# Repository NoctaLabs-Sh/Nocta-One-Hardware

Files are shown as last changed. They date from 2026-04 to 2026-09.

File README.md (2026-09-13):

# Nocta Hardware

Open hardware for the Nocta vault: an offline password and credential manager
with a 2.7 inch e-ink screen, optional Bluetooth LE, and no cloud service
behind it.

This repository is the design, not a product. The device is a prototype, it is
not for sale, and there is no ship date.

Built by [Nocta Labs](https://noctalabs.sh), Leuven, Belgium.

## What is in here

| Path | What it is |
| --- | --- |
| `Hardware/OpenVault.kicad_sch` | Schematic, KiCad |
| `Hardware/Schematic.pdf` | The same schematic, readable without KiCad |
| `Hardware/OpenVault.kicad_pcb` | Board layout, KiCad |
| `Hardware/production/` | Fabrication packages: gerbers, positions, BOMs |
| `Hardware/3D/` | STEP models for individual component packages |
| `Hardware/Datasheets/` | Datasheets for the parts used |
| `Hardware/Footprints/`, `Symbols/` | Project libraries |

## What is not in here yet

- **Firmware.** Still being written. It will be published when it is worth
  reading, and the licence for it is not decided.
- **The enclosure.** No named enclosure model is published yet.
- **Photographs.** Coming with the next write-up.

## Licence

[CERN Open Hardware Licence Version 2, Strongly Reciprocal](LICENSE)
(`CERN-OHL-S-2.0`). Strongly reciprocal means anything you make from this and
distribute has to stay open under the same terms. That is deliberate.

## Reading the files

Open `Hardware/OpenVault.kicad_pro` in KiCad 8 or later, or start with
`Hardware/Schematic.pdf` if you just want to read it. The fabrication packages
under `Hardware/production/` are what actually went to the board house.

## Use of AI

AI assistance, primarily Anthropic's Claude, is used in the development of this
hardware.

Its role is limited to review and analysis: reading datasheets and verifying pin
assignments and component values against them, reviewing the schematic and the
board layout, triaging ERC and DRC output, maintaining helper scripts, and
drafting documentation.

Component selection, the board stackup, the USB differential pair impedance and
all security related decisions are made by the maintainers. No AI system commits
to this repository, and every change is reviewed by a maintainer before it
reaches `main`.

No part of this design has been validated by an AI system, and maintainer review
does not amount to electrical or security qualification. The design should be
read against the component datasheets and verified independently before
fabrication or use. The warranty and liability disclaimers in the licence apply
in full.

Contributions developed with AI assistance are accepted, provided the use is
disclosed in the pull request and the contributor can account for the work
submitted.

## Telling us we are wrong

Open an issue. A mistake found in the schematic now is worth more to us than
a compliment later :)

For anything sensitive, mail hello@noctalabs.sh first and we will credit you
publicly once it is fixed.

## Related

- [noctalabs.sh](https://noctalabs.sh) and its [security page](https://noctalabs.sh/security)
- [The blog](https://noctalabs.sh/blog), where revisions get written up

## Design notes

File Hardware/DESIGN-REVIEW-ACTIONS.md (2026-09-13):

# OpenVault — Design Review Actions

Review date: 2026-08-02 · KiCAD 10.0.3 · Board rev "V3" (45.00 × 69.00 mm, 4-layer)

Status after this review: **0 DRC errors, 9 warnings.** All findings below were verified against
`kicad-cli` output, the board geometry, and the nPM1300 / STM32WB5MMG / TPS62840 datasheets.

> Verification note: DRC must be run with `--refill-zones`. The on-disk zone fills were stale and
> produced 30 phantom violations and 71 phantom unconnected items. **Fill All Zones (Ctrl+B) and save.**
>
> ```
> /Applications/KiCad/KiCad.app/Contents/MacOS/kicad-cli pcb drc Hardware/OpenVault.kicad_pcb \
>   -o /tmp/drc.json --format json --severity-all --refill-zones --schematic-parity --units mm
> ```

---

## 1. CRITICAL — nPM1300 BUCK input decoupling

### The problem

IC1 `PVDD` (pin 4, the BUCK power input) is at **(146.35, 87.925)**. Every capacitor on the `VSYS`
net is clustered near U2, ~17 mm away:

| Cap | Value | Distance to IC1 PVDD |
|-----|---|---|
| C3  | 10 µF | **17.41 mm** |
| C4  | 10 µF | **17.83 mm** |
| C26 | 4.7 µF | **17.86 mm** |

**IC1 has no input capacitor near it at all.** This is BUCK2's input loop — the converter that makes
your main **+3V3 logic rail**. At roughly 1 nH/mm, a 17 mm out-and-back loop is 30+ nH; a 0.2 A
switching edge in 5 ns puts on the order of a volt of spike on PVDD. Expect ringing, EMI, and
degraded regulation.

Nordic, §9.3.4 PCB guidelines:

> "The BUCK supply voltage should be decoupled with high performance capacitors **as close as
> possible to the supply pins**. Long power supply lines on the PCB should be avoided. All device
> grounds, VDD connections, and VDD bypass capacitors **must be connected as close as possible to
> the device**."

Their reference BOM (Table 42) pairs a **10 µF** bulk with a **100 nF 0201** at the pin.

### Status: C3 moved ✅ (2026-08-02)

C3 relocated (142.25, 71.775) → **(146.35, 83.55)**. Distance to PVDD: **17.41 mm → 3.60 mm**.
Roughly a 5× cut in the feed-side inductance. It cannot easily go closer — L1 occupies the space
directly left of the QFN (correctly, the SW node must stay short) and VOUT2 (pin 32) sits above.
**3.6 mm is acceptable for the bulk cap.** Leave it.

Leave **C4** (10 µF bulk) and **C26** (4.7 µF) where they are — C26 at 2.40 mm is correctly serving
as the TPS62840's `CI`, which its datasheet specifies as 4.7 µF.

### Why a 10 µF alone cannot work here — f_BUCK = 3.6 MHz

Every MLCC is C in series with its ESL, so it only decouples **below** its self-resonant frequency
`SRF = 1/(2π√(L·C))`. Above SRF it is an inductor.

**C3 as installed:**

| Term | Value |
|---|---|
| 10 µF 0603 X5R at ~3.7 V DC bias (derating) | C_eff ≈ 5 µF |
| MLCC ESL | ~0.9 nH |
| 3.6 mm feed to PVDD (~1 nH/mm) | ~3.6 nH |
| Return path — nearest PVSS GND via is 2.4–2.8 mm | ~2.5 nH |
| **Total loop** | **≈ 7 nH** |

`SRF = 1/(2π√(7 nH × 5 µF))` ≈ **850 kHz**.

**The BUCK switches at 3.6 MHz** (datasheet §6.3.6, f_BUCK, PWM mode). C3 is operating ~4× above
its own resonance — at the switching frequency it is inductive. It does bulk energy storage and
low-frequency ripple, and contributes **nothing** at 3.6 MHz.

**A 100 nF 0402 at ~1.5 mm with its own ground via:** C_eff ≈ 85 nF (little bias derating),
ESL ~0.5 nH + mounting ~0.5 nH + 1.5 mm feed ~1.5 nH + local via return ~0.3 nH ≈ 2.8 nH
→ **SRF ≈ 10 MHz**. That covers 3.6 MHz and its second harmonic — exactly the band C3 cannot serve.

This is why moving C3 alone does not fix the problem. The 100 nF is not extra insurance; **it is the
part that does the actual work at the switching frequency.**

### Add — capacitors ✅ added to schematic 2026-08-02

| Ref | Value | Footprint | LCSC | Net |
|-----|---|---|---|-----|
| **C29** | 100 nF | C_0402_1005Metric | C1525 | `VSYS` ↔ `GND` (decouples `PVDD`, pin 4) |
| **C30** | 100 nF | C_0402_1005Metric | C1525 | `+3V3` ↔ `GND` (decouples `VDDIO`, pin 12) |

Note: `PVDD` **is** the `VSYS` net and `VDDIO` **is** the `+3V3` net — there is no separate net to
attach to. The decoupling is created entirely by **PCB placement**, not by the schematic connection.

There was previously **no small-value HF capacitor anywhere on `VSYS`** — only 0603/0805 bulk.

### PCB placement (free-space scanned against real pad geometry, 0.15 mm clearance)

| Ref | Place at | Rot | Distance to pin |
|-----|---|-----|---|
| **C29** | **(145.00, 89.45)** | 0 | **2.04 mm** to PVDD (~1.6 mm copper-to-copper) |
| **C30** | **(148.15, 93.00)** | 0 | 2.41 mm to VDDIO |

C29: put the pad **nearest IC1** on `VSYS`; the far pad on `GND`. It also sits 1.45 mm from PVSS2
(pin 6), which is what you want for the return. Estimated loop ≈ 3.3 nH → **SRF ≈ 9.5 MHz**,
comfortably above the 3.6 MHz switching frequency.

**0201 alternative:** the 0.89 mm gap left of the QFN misses fitting a 0402 by 0.03 mm (needs
0.92 mm). An 0201 fits at **(145.55, 87.60) rot 90 → 0.86 mm** from PVDD (SRF ≈ 12.4 MHz), matching
Nordic's reference exactly (their C13 is a 100 nF **0201**). Better, but not decisive, and 0201 is
unpleasant to hand-rework. Take it only if matching the reference matters — change the footprint to
`C_0201_0603Metric`.

C30 at 2.41 mm is fine: VDDIO is a low-current logic supply for TWI/GPIO, not a switching node.

Board is **single-sided assembly** (no B.Cu components), so a bottom-side cap under pin 4 was
rejected — it would force a second assembly setup for one part.

### Add — vias (equally important, currently missing)

**1. Exposed-pad thermal vias — there are currently ZERO.**
The 3.6 × 3.6 mm EP is `AVSS`: both the device's analog ground reference *and* its only thermal path.
Today it reaches In1.Cu only by spreading laterally through the F.Cu pour to a via ~1.5 mm outside
the pad. That is poor for ground impedance and poor for heat during charging (thermal shutdown is
120 °C).

→ Add a **3 × 3 array of vias at ~1.0 mm pitch inside the EP**, using the existing 0.45 mm / 0.2 mm
stack so no new drill size and no upcharge. The small drill also limits solder wicking; if you want
belt-and-braces, JLCPCB offers epoxy-filled/capped via-in-pad as a paid option.

**2. Local ground vias at PVSS1 / PVSS2.**
Nearest GND via is **2.80 mm** from pin 2 and **2.37 mm** from pin 6, so the return current runs
that far sideways on F.Cu before reaching the plane — roughly +2.5 nH, which nearly doubles the loop.

→ Place one GND via **immediately at** each of pin 2 and pin 6. In1.Cu is only 0.2 mm below F.Cu, so
a via there is ~0.3 nH. **This single change benefits both C3 and the new 100 nF**, and is the
cheapest inductance you will ever buy back.

### Layout rules for the rework

- Keep the PVDD → cap → PVSS loop area minimal; cap on the same layer, no vias in the *feed* path.
- Ground the caps with their **own** via straight down to In1.Cu — never route ground laterally on F.Cu.
- L1 (2.2 µH, datasheet nominal) stays tight to `SW2` (pin 5) — it already is. Do not disturb it.

---

## 2. CRITICAL — Timekeeping architecture

### The constraint

Three verified facts combine badly:

1. STM32 `VBAT` (pin 15) is tied to **+3V3** — no independent backup domain supply.
2. nPM1300 Ship/Hibernate modes **"disconnect the battery from the system"** → VSYS drops → BUCK2 off → +3V3 off.
3. Therefore the RTC backup domain loses power and **wall-clock time is lost on every power-down.**

The nPM1300's own TIMER does not help: it is a 24-bit countdown *wake* timer, not a calendar, and at
the default 16 ms tick it maxes out around 3 days.

This matters because **TOTP (RFC 6238)** is dead without a trustworthy clock.

### Layer A — Stop using Ship mode as "off" *(this revision, one rework)*

Use **STM32 STOP2 with LSE + RTC running** as the idle/off state. Reserve nPM1300 Ship mode for
factory shipping and long-term storage only.

| State | Current |
|---|---|
| STM32 STOP2 + RTC | ~1–2 µA |
| nPM1300 quiescent (I_QBAT) | 800 nA |
| TPS62840 disabled | ~60 nA |
| **Total** | **~3 µA** |

**Blocker: `+3V3_EINK` is always on.** U2's `EN` (pin 4) is strapped to `VSYS`, so the e-ink panel's
`VDDIO`/`VCI` stay powered in STOP2. Panel standby is typically µA–mA and would swamp the 3 µA budget.

**Rework:** cut `EN` from `VSYS`; drive it from a free STM32 GPIO. Free, unrouted pads on the board
include PA0(3), PA4(55), PC0(12), PC1(9), PC2(8), PC3(7), PD0(33), PD1(34), PE0(79), PE1(64).

Safe by construction: on MCU reset the GPIO goes high-Z and the TPS62840's internal 450 kΩ pulldown
disables the rail. E-ink retains its image with no power, so dropping the rail costs nothing visually.

### Layer B — Back up the VBAT domain *(next revision)*

Survives battery depletion and cell swaps:

- Cut pin 15 from +3V3
- Feed via a Schottky from +3V3, with a supercap to GND

Sizing: `t = C·ΔV/I`. VBAT domain draws ~0.5–1 µA; usable swing 3.3 V → 1.55 V.
**0.22 F ≈ 4–9 days**; **1 F ≈ weeks**. Measure actual VBAT current at bring-up and size from that.

### Layer C — Calibration and resync *(firmware, required regardless)*

A ±20 ppm LSE drifts **1.7 s/day, 52 s/month**. TOTP's ±30 s window breaks in **2–4 weeks**.

- **`RTC_CALR` smooth calibration** (±488 ppm range, 0.954 ppm steps). Measure drift against host time
  over a known interval, store the trim in flash, apply at boot. Gets to a few ppm — months between resyncs.
- **Resync on every USB attach.** Use `RTC_ISR.INITS` to detect a cold backup domain; mark TOTP
  unavailable until resynced.
- **Enforce monotonicity.** A malicious host setting the clock forward harvests future TOTP codes.
  Never accept time going backwards; surface large jumps to the user.
- **Verify the "32.774 kHz" figure** in the module datasheet (§3.3) empirically — almost certainly a
  typo for 32.768, but taken literally it is +183 ppm ≈ 16 s/day. A 24 h run against host time both
  confirms it and yields the calibration constant.

### Do you need a TCXO RTC?

Only if TOTP must work standalone for months with no host. A DS3231M (±5 ppm ≈ 13 s/month, own VBAT
pin) would do it. **Recommendation: skip it** — a password manager sees a host regularly, and A+B+C
covers the requirement without another part or attack surface.

---

## 3. Other decoupling placement fixes

All are *moves* of existing parts unless noted.

| Ref | Value | Currently | Target | Why |
|-----|---|---|---|-----|
| **C6** | 2.2 µF | 8.0 mm from IC1 `VBAT`(19) | **< 2 mm** | Correct value per Nordic ref BOM, wrong place |
| **C2** | 1 µF | 15.1 mm from IC1 `VBUS`(21) | **< 2 mm** | USB input decoupling |
| **C25** | 100 nF | 9.16 mm from U3 `VCC`(8) | **< 2 mm** | SPI flash at 50–100 MHz needs local HF decoupling |
| C5 / C1 | 10 µF | 5.1 / 6.3 mm from `VOUT2`(32) | ≤ 3 mm | BUCK2 output; less critical than input |

Already good — **do not move**: C1 → `VDDIO` 1.78 mm · IC2 +3V3 1.75 mm · IC3 +3V3 1.18 mm.

---

## 4. Schematic fixes

| Item | Action |
|---|---|
| **VOUT1 (pin 1) tied to VSYS** | **Leave unconnected.** BUCK1 is correctly disabled (VSET1 grounded = "0 V OFF" per Table 18), but active discharge is *forced* on power-cycle reset — 2 kΩ ≈ 2 mA parasitic load on VSYS |
| ~~C15 / C18 pin 2~~ | **RETRACTED — not a real defect.** KiCAD's ERC is **nondeterministic on this schematic**: three runs on an identical file gave 35 / 33 / 35 violations, with `pin_not_connected` varying between 1 and 3 and naming different caps each time (C15/C18/C20, then C16/C19/C20, then only C15). The netlist consistently shows all of them connected. **Never gate a decision on a single ERC run — run it several times, or trust the netlist.** Worth a brief visual check of that cap cluster, but low priority |
| **U2 symbol pin types** | All pins are typed *Unspecified* — this alone generates 12 spurious ERC warnings. Set correct electrical types |
| **VBAT `power_pin_not_driven`** | Add a PWR_FLAG (battery connector pins are passive) |
| **`PVSS2` label on GND** | Drop the redundant label |
| **TP1–TP8** | No footprints assigned, not on board. Assign, or tick *Exclude from board* |

---

## 5. PCB / DRC cleanup (9 warnings)

| Item | Count | Action |
|---|---|---|
| Clearance violations, 0.09–0.14 mm vs 0.15 mm netclass | 9 | Reroute. Clusters at (129.6–132.8, 98.0–99.6) and (139.1–142.1, 93.3–93.9) |
| `missing_courtyard` | 6 | Add F.CrtYd to L1, L3, U2, J03, J4, SW2 |
| `lib_footprint_mismatch` | 2 | IC2 and SW2 — both expected, see §6 |
| `lib_footprint_issues` | 1 | `SamacSys_Parts` not in `fp-lib-table`; move IC1's footprint into `OpenVaultFootprints.pretty` |
| `fp-lib-table` dead entry | 1 | Delete `.pretty` → `C:/Users/byte/Downloads/.pretty.pretty` |

---

## 6. Deliberate deviations — do NOT "fix"

**IC2: 17 LGA lands removed on purpose.** Board copy has 69 pads, library has 86. Missing:
`1, 2, 42, 43, 44, 56, 61, 62, 63, 72–78, 83` (plus IC1 pad 8 / GPIO1). All are unused GPIO carrying
no net — verified against netlist and datasheet. Ten sites have copper routed beneath: `SECURE_CSN`
(42, 43), `DISPLAY_CSN` (72–74), `MCU_SPI_MOSI` (75), `MCU_SPI_SCK` via (76), `GND` (61, 62, 77).

Safe at fab and assembly — no pad means no stencil aperture, so no solder is deposited there.

- **Never run Tools → Update Footprints from Library on IC2.** It restores all 86 pads while the
  traces stay, shorting unused GPIO to the SPI chip-selects.
- The permanent `lib_footprint_mismatch` on IC2 records this state.
- DRC is blind to this region forever. An F.Cu keepout over those land sites would make it enforceable.

**SW2 mounting holes** were converted `thru_hole` → `np_thru_hole` during this review (they had
drill 0.8 mm = pad 0.8 mm, i.e. zero annular ring). That cleared 4 errors. The resulting
`lib_footprint_mismatch` on SW2 is expected until the fix is pushed back to the library.

**IC3 footprint clearance override of 0.19 mm** was removed — it exceeded the TROPIC01's own
0.15 mm pad-to-EP gap, so the part could never satisfy its own rule.

---

## 7. Verified correct — leave alone

| Block | Evidence |
|---|---|
| **Antenna** | Planes cut back to Y≈55.18: **3.5 mm** from board edge, **2.7 mm** into module. Matches both numbers in ST Figure 4 (1.3 mm edge offset / 2.5 mm clearance). `ANT_IN`+`RF_OUT` grounded and `ANT_NC` soldered to an unconnected pad — all three explicitly required by §6.1 |
| **USB** | `USBD±` skew **0.000 mm**; `P_USBD±` 3.0 mm (USB 2.0 budget ≈ 15 mm); **zero vias** — no impedance discontinuities. USBLC6 orientation correct (D− 1→6, D+ 3→4) |
| **BUCK2** | VSET2 = 330 kΩ → 3.3 V (Table 19); L1 = 2.2 µH = datasheet nominal |
| **TPS62840** | R4 = 267 kΩ → 3.3 V (Table 1, E96 nominal, band 256.32–277.68 kΩ). MODE/STOP terminated, EN valid. VSET parasitic C ≈ **0.15 pF** vs 100 pF limit (~228× margin), 0.75 mm from SW node |
| **E-ink booster** | Complete: L2 10 µH, Q1 NMOS, R3 0.47 Ω sense, R2 10 kΩ gate pulldown, D1/D2/D3 charge pump → PREVGH/PREVGL, all six panel rails decoupled |
| **MCU support** | BOOT0 = 10 kΩ to **GND**; NRST 100 nF; SWD on TC2030; all supply pins correct (pin 17 is `VDD`, the symbol's "VDDSMPS" label is a naming quirk) |
| **SHPHLD** | Button to GND; 50 kΩ **internal** pull-up (Table 33). Datasheet §8.7 literally describes "SHPHLD is connected to SW2" |
| **I²C / flash** | 4.7 kΩ pull-ups both lines; flash CS 10 kΩ pull-up; WP#/HOLD# tied high |

---

## 8. Firmware requirements

- **`RCC_BDCR_LSEDRV[1:0] = 10`** (medium-high drive) — required by module datasheet §3.3 for the
  integrated LSE. Miss it and the crystal may not start reliably.
- **`HSEGMC[2:0] = 0b011`**; do **not** modify `RCC_HSECR` — HSE is factory-tuned, loaded by hardware.
- No clock bypass mode — both crystals are internal to the SiP.
- Check `RTC_ISR.INITS` at boot to detect a cold backup domain.

---

## 9. Security checklist (hardware password manager)

- **RDP Level 2 permanently disables SWD**, and J5 (TC2030) is the only debug path. Once burned the
  device is unflashable — plan provisioning first.
- **Rollback protection:** an attacker can snapshot W25Q128, burn PIN attempts, and restore it. The
  monotonic try counter must live in TROPIC01 or STM32 internal flash — never solely on external flash.
- **Everything on W25Q128 needs AEAD** (AES-GCM / ChaCha20-Poly1305), not bare encryption.
- **PIN verification must happen inside TROPIC01**, with the secure element owning rate limiting.
- **Host-supplied time is attacker-controlled** — see §2 Layer C monotonicity rule.
- **BLE is remote attack surface** on a vault device — decide deliberately whether it ships enabled.
- Configure BOR so brownout during unlock resets cleanly rather than executing at marginal supply.

---

## 10. Suggested order

1. **This revision (rework):** ~~C3 move~~ ✅ · 100 nF at PVDD · 100 nF at VDDIO · 9 EP thermal vias · GND vias at PVSS1/PVSS2 · U2 `EN` → GPIO
2. **This revision (schematic):** VOUT1 disconnect · C15/C18 check · U2 pin types
3. **Firmware:** LSE drive setting · RTC calibration + resync + monotonicity
4. **Cleanup:** 9 clearance spots · courtyards · lib tables · test points
5. **Next spin:** VBAT backup supercap · remaining decoupling moves (C6, C2, C25) · F.Cu keepout over IC2's removed lands

---

## 11. Open items

- **E-ink panel datasheet not in repo** — rail voltages inferred from booster topology only.
  Driver family inferred as SSD16xx/UC8xxx-style from the GDR/RESE/PREVGH/PREVGL/BS pinout.
- **Battery spec / power budget undocumented** — cannot sanity-check charge settings or rail sizing.
- **`Hardware/.step` and `Hardware/.stl`** (4.4 MB / 3.5 MB) are committed files with empty basenames
  from a bad 3D export, referenced by nothing.

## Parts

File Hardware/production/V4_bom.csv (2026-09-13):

Designator | Footprint | Quantity | Value | LCSC Part #
C1 | 0805 | 1 | 4u7 | C1779
C10, C3 | 0402 | 2 | 1uF | C52923
C11, C13, C14, C19, C20, C21, C24, C25, C27 | 0805 | 9 | 4u7/25V | C1779
C12, C15, C16, C17, C18 | 0402 | 5 | 100nF | C1525
C2, C5, C7, C8 | 0603 | 4 | 10uF | C19702
C22, C23, C26, C28 | 0603 | 4 | 1uF/50V | C15849
C4, C6 | 0805 | 2 | 22uF/25V | C45783
C9 | 0603 | 1 | 2u2 | C23630
D1, D2, D3 | D_SOD-123 | 3 | MBR0530 | C77336
IC1 | QFN-32-1EP_5x5mm_P0.5mm_EP3.45x3.45mm_ThermalVias | 1 | NPM1300-QEAA-R | C7466043
IC2 | ST-SiP-LGA-86-11x7.3mm | 1 | STM32WB5MMGH6TR | C5184586
J04 | FPC-SMD_24P-P0.50_HC-FPC-05-09-24RLTAG | 1 | HC-FPC-05-09-24RLTAG | C5213757
J1 | USB_C_Receptacle_GCT_USB4105-xx-A_16P_TopMnt_Horizontal | 1 | USB_C_Receptacle_USB2.0_16P | C2765186
J2 | JST_SH_SM03B-SRSS-TB_1x03-1MP_P1.00mm_Horizontal | 1 | BATT_CON | C160403
J3 | FPC-SMD_AFC01-S06FCC-00 | 1 | JUSHUO AFC01-S06FCC-00 | C262262
L1, L2 | IND-SMD_L2.0-W1.6 | 2 | 2.2uH | C71386
L3 | L_Sunlord_SWPA4030S | 1 | 10uH1A | C497803
Q1 | SOT-323_SC-70 | 1 | Si1308EDL | C7603347
R1 | 0603 | 1 | 330K | C23137
R2 | 0402 | 1 | 267K | C270622
R3, R6, R7 | 0603 | 3 | 10K | C25804
R4, R5 | 0603 | 2 | 4.7K | C23162
R8 | 0603 | 1 | 0R47 | C23411
SW1 | KEY-SMD_4P-SKSCLXX010 | 1 | SKSCLBE010 | C115361
U1 | SOT-23-6 | 1 | USBLC6-2SC6 | C2687116
U2 | VSON-8_L2.0-W1.5-P0.50-BL | 1 | TPS62840DLCR | C2071859
U3 | SOIC-8_5.3x5.3mm_P1.27mm | 1 | W25Q128JVS | C97521

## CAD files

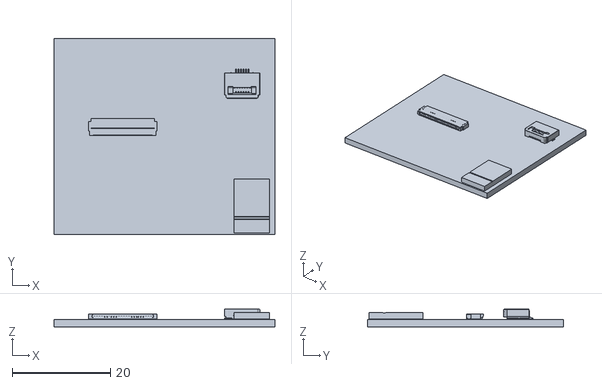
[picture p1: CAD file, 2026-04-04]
Hardware/.stl
45.0 x 40.0 x 3.60

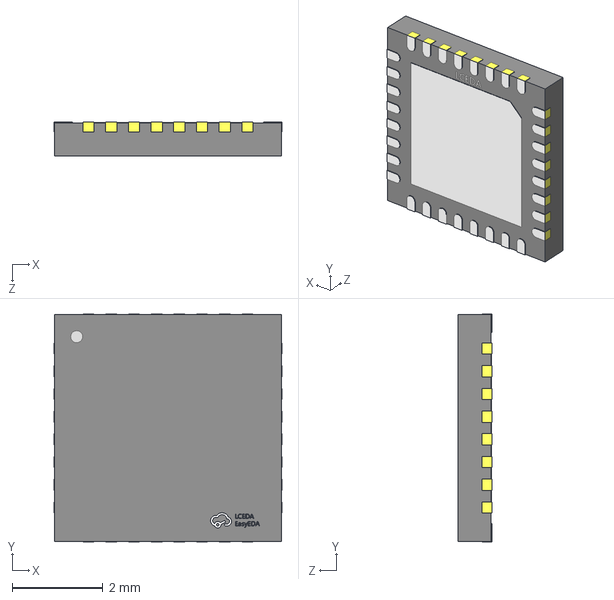
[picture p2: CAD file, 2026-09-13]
Hardware/3D/TQFN-32_L5.0-W5.0-P0.50-BL-EP3.5.step
5.02 x 5.02 x 0.751 mm

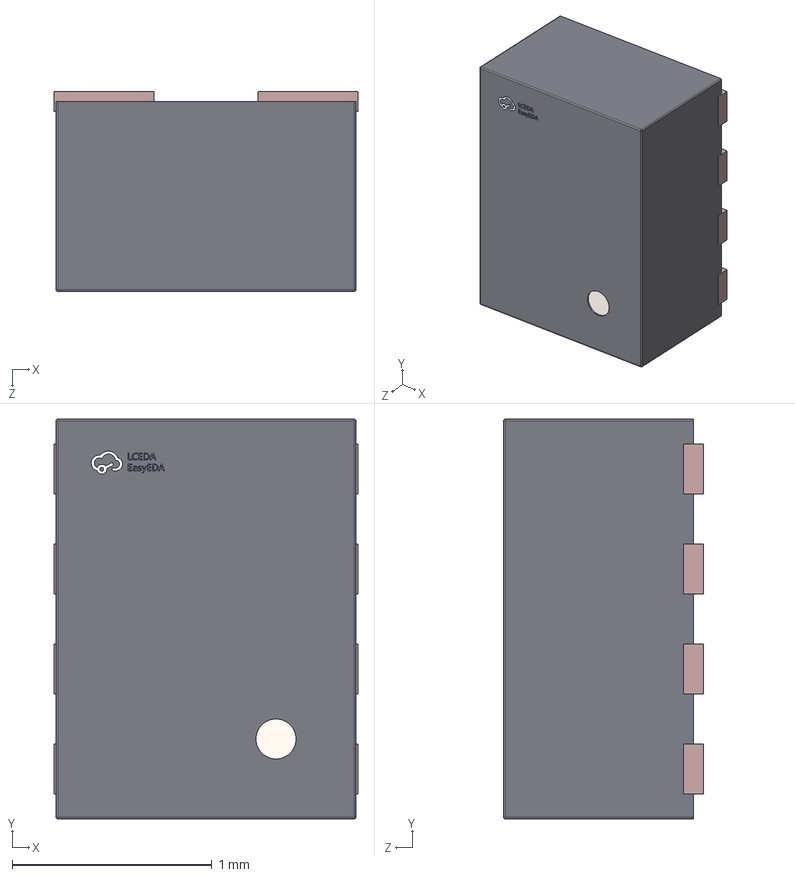
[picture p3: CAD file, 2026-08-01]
Hardware/3D/VSON-8_L2.0-W1.5-H1.0-P0.50-BL.step
1.52 x 2.00 x 1.00 mm

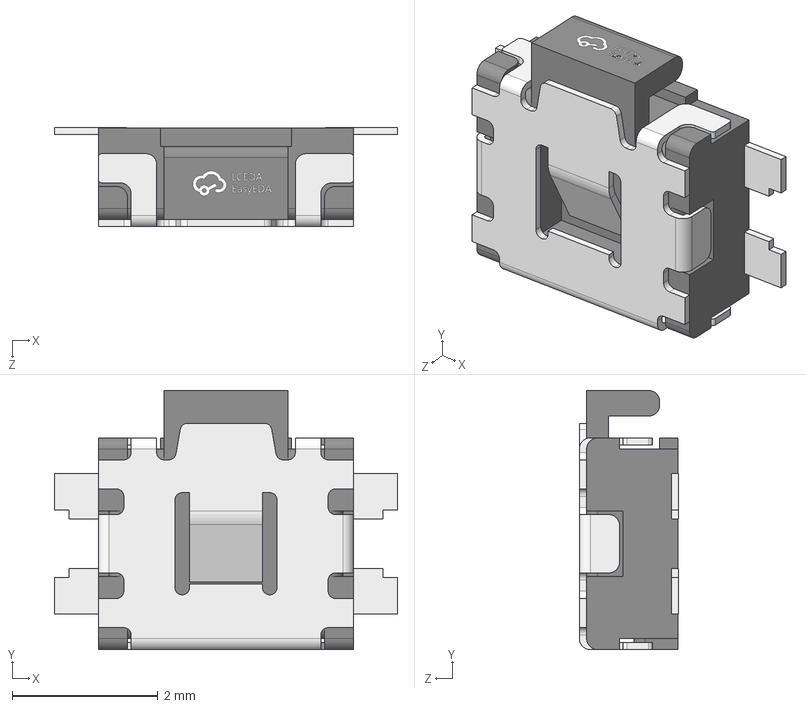
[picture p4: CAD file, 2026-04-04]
Hardware/3D/KEY-SMD_4P-L3.5-W3.6-H1.3-LS4.8-P1.3.step
4.70 x 3.55 x 1.36 mm

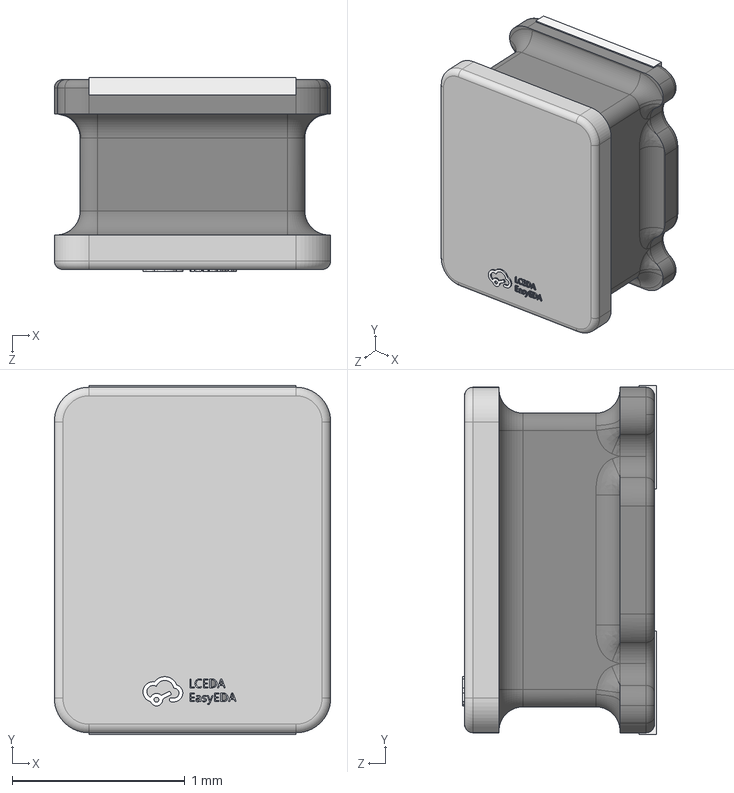
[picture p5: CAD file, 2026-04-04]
Hardware/3D/IND-SMD_L2.0-W1.6-H1.1.step
1.60 x 2.02 x 1.12 mm

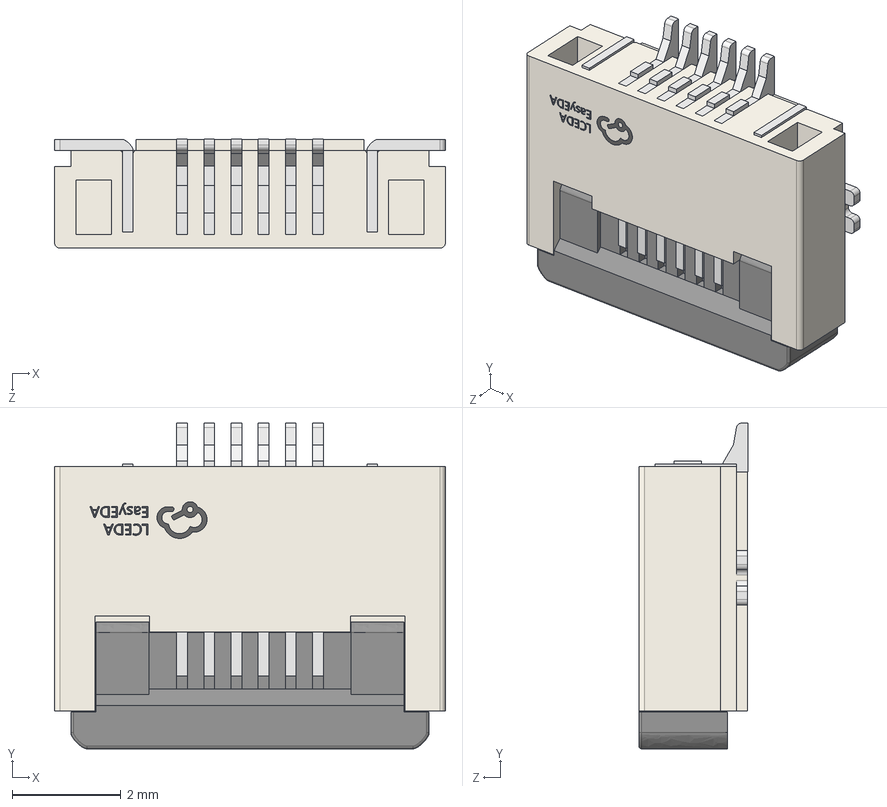
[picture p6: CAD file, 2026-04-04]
Hardware/3D/FPC-SMD_P0.50-WS-6P.step
7.20 x 6.00 x 2.01 mm

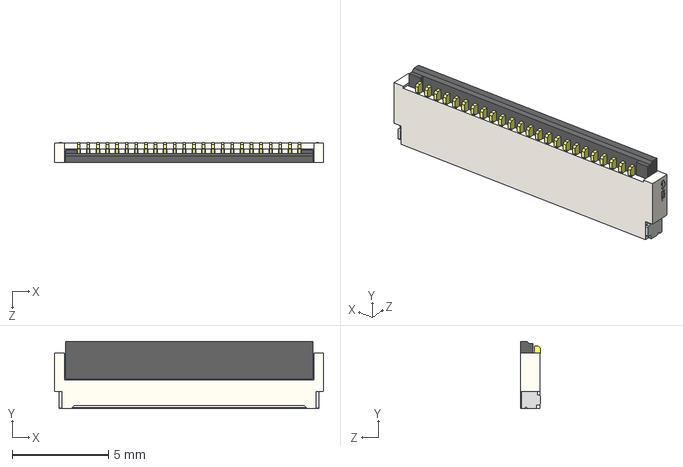
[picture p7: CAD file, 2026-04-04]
Hardware/3D/FPC-SMD_24P-P0.50_HC-FPC-05-09-24RLTAG.step
14.0 x 3.50 x 1.02 mm

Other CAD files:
Hardware/.step

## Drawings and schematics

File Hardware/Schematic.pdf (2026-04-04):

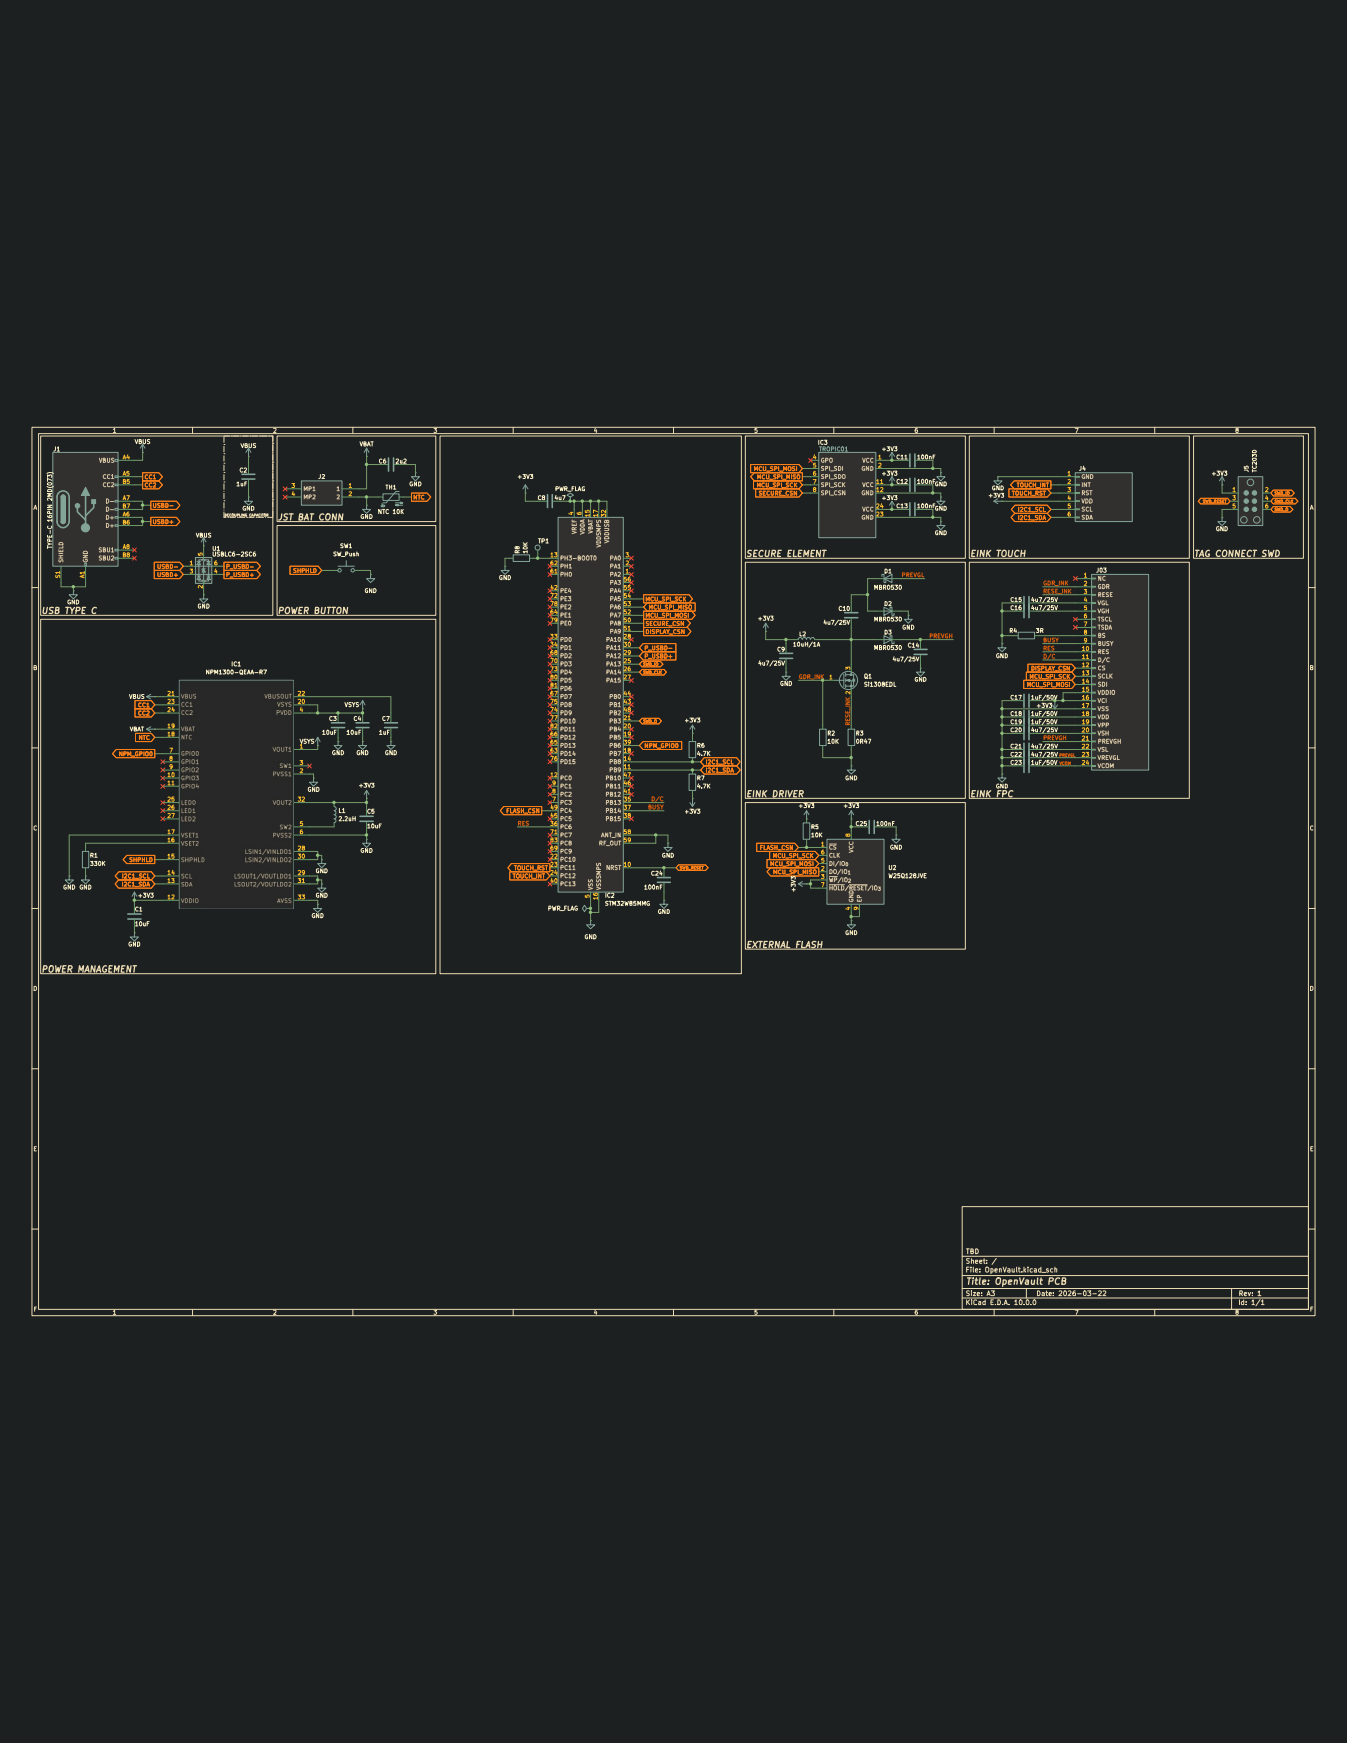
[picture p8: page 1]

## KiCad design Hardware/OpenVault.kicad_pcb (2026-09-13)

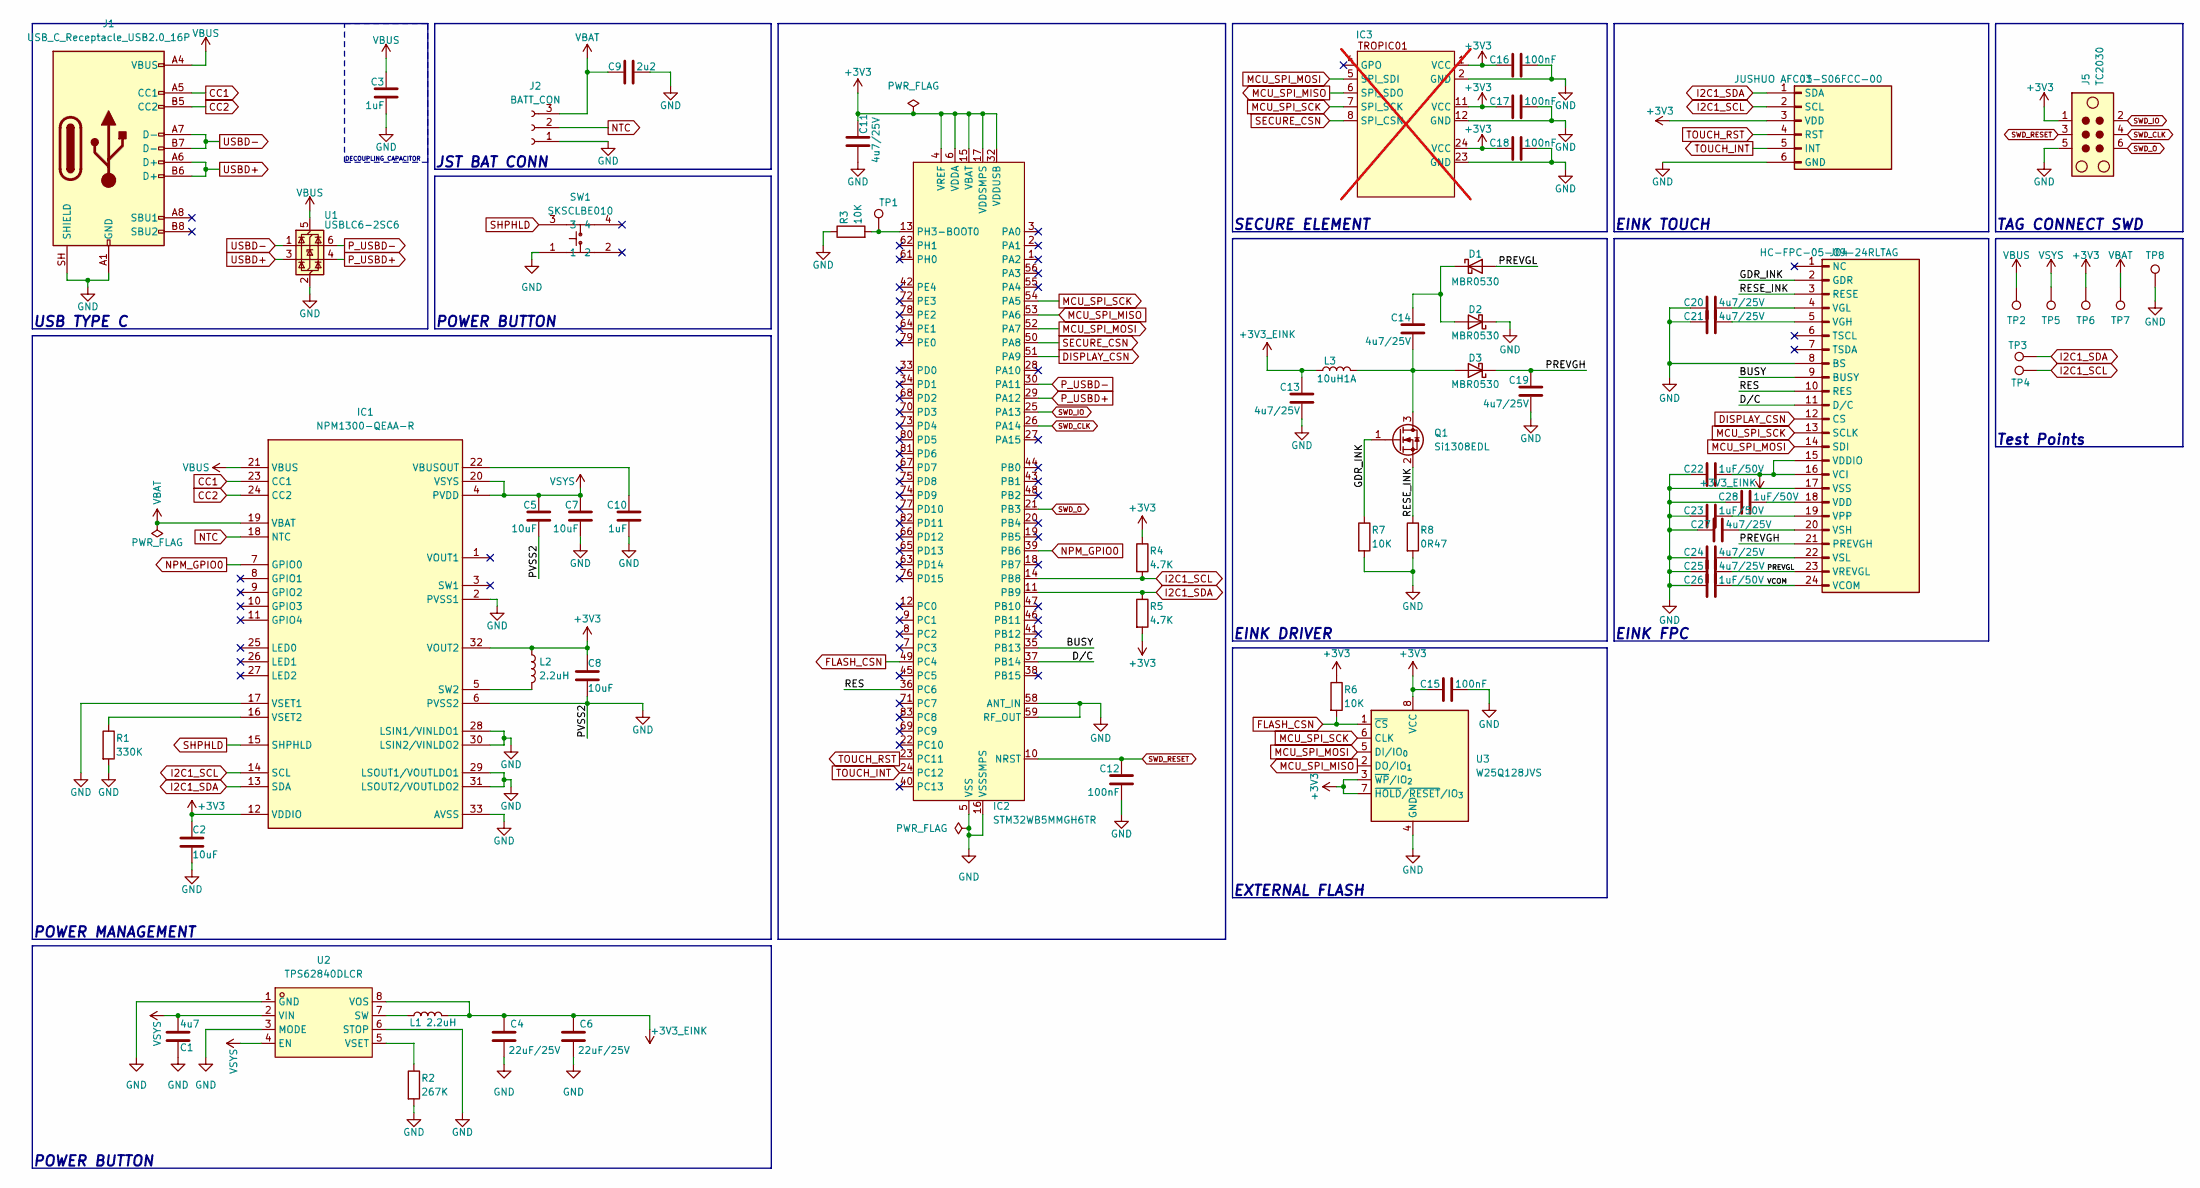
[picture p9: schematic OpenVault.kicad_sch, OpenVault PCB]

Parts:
C1: 4u7; C_0805_2012Metric; LCSC C1779
C2, C5, C7, C8: 10uF; C_0603_1608Metric; LCSC C19702
C3, C10: 1uF; C_0402_1005Metric; LCSC C52923
C4, C6: 22uF/25V; C_0805_2012Metric; LCSC C45783
C9: 2u2; C_0603_1608Metric; LCSC C23630
C11, C13, C14, C19, C20, C21, C24, C25, C27: 4u7/25V; C_0805_2012Metric; LCSC C1779
C12, C15, C16, C17, C18: 100nF; C_0402_1005Metric; LCSC C1525
C22, C23, C26, C28: 1uF/50V; C_0603_1608Metric; LCSC C15849
D1, D2, D3: MBR0530; D_SOD-123; LCSC C77336
IC1: NPM1300-QEAA-R; QFN-32-1EP_5x5mm_P0.5mm_EP3.45x3.45mm_ThermalVias; Manufacturer_Part_Number NPM1300-QEAA-R7; Mouser Part Number 949-NPM1300-QEAA-R7
IC2: STM32WB5MMGH6TR; ST-SiP-LGA-86-11x7.3mm; LCSC C5184586
IC3: TROPIC01; QFN-32-1EP_4x4mm_P0.4mm_EP2.9x2.9mm; not fitted
J1: USB_C_Receptacle_USB2.0_16P; USB_C_Receptacle_GCT_USB4105-xx-A_16P_TopMnt_Horizontal; LCSC C2765186
J2: BATT_CON; JST_SH_SM03B-SRSS-TB_1x03-1MP_P1.00mm_Horizontal; LCSC C160403
J3: JUSHUO AFC01-S06FCC-00; FPC-SMD_AFC01-S06FCC-00; LCSC C262262
J04: HC-FPC-05-09-24RLTAG; FPC-SMD_24P-P0.50_HC-FPC-05-09-24RLTAG; LCSC C5213757
J5: TC2030; Tag-Connect_TC2030-IDC-NL_2x03_P1.27mm_Vertical
L1, L2: 2.2uH; IND-SMD_L2.0-W1.6; LCSC C71386
L3: 10uH1A; L_Sunlord_SWPA4030S; LCSC C497803
Q1: Si1308EDL; SOT-323_SC-70; LCSC C7603347
R1: 330K; R_0603_1608Metric; LCSC C23137
R2: 267K; R_0402_1005Metric; LCSC C270622
R3, R6, R7: 10K; R_0603_1608Metric; LCSC C25804
R4, R5: 4.7K; R_0603_1608Metric; LCSC C23162
R8: 0R47; R_0603_1608Metric; LCSC C23411
SW1: SKSCLBE010; KEY-SMD_4P-SKSCLXX010; LCSC C115361
TP1, TP2, TP3, TP4, TP5, TP6, TP7, TP8: TestPoint; TestPoint_Pad_D1.0mm
U1: USBLC6-2SC6; SOT-23-6; LCSC C2687116
U2: TPS62840DLCR; VSON-8_L2.0-W1.5-P0.50-BL; LCSC Part C2071859
U3: W25Q128JVS; SOIC-8_5.3x5.3mm_P1.27mm; LCSC C97521

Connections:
+3V3: C2.2, C8.2, C11.1, C15.1, C16.1, C17.1, C18.1, IC1.12 (VDDIO), IC1.32 (VOUT2), IC2.4 (VREF), IC2.6 (VDDA), IC2.15 (VBAT), IC2.17 (VDDSMPS), IC2.32 (VDDUSB), IC3.1 (VCC), IC3.11 (VCC), IC3.24 (VCC), J3.3 (VDD), J5.1, L2.1, R4.1, R5.2, R6.1, TP6.1 (1_1), U3.3 (~WP/IO_{2}), U3.7 (~HOLD/~RESET/IO_{3}), U3.8 (VCC)
+3V3_EINK: C4.1, C6.1, C13.1, C22.2, J04.15 (VDDIO), J04.16 (VCI), L1.2, L3.1, U2.8 (VOS)
/BUSY: IC2.35 (PB13), J04.9 (BUSY)
/D/C: IC2.37 (PB14), J04.11 (D/C)
/GDR_INK: J04.2 (GDR), Q1.1 (G), R7.1
/PREVGH: C19.1, D3.1 (K), J04.21 (PREVGH)
/PREVGL: C25.2, D1.2 (A), J04.23 (VREVGL)
/RES: IC2.36 (PC6), J04.10 (RES)
/RESE_INK: J04.3 (RESE), Q1.2 (S), R8.1
/VCOM: C26.2, J04.24 (VCOM)
CC1: IC1.23 (CC1), J1.A5 (CC1)
CC2: IC1.24 (CC2), J1.B5 (CC2)
DISPLAY_CSN: IC2.51 (PA9), J04.12 (CS)
FLASH_CSN: IC2.49 (PC4), R6.2, U3.1 (~CS)
GND: C1.1, C2.1, C3.2, C4.2, C5.2, C6.2, C7.2, C8.1, C9.2, C10.2, C11.2, C12.2, C13.2, C15.2, C16.2, C17.2, C18.2, C19.2, C20.1, C21.1, C22.1, C23.1, C24.1, C25.1, C26.1, C27.1, C28.1, D2.1 (K), IC1.2 (PVSS1), IC1.6 (PVSS2), IC1.17 (VSET1), IC1.28 (LSIN1/VINLDO1), IC1.29 (LSOUT1/VOUTLDO1), IC1.30 (LSIN2/VINLDO2), IC1.31 (LSOUT2/VOUTLDO2), IC1.33 (AVSS), IC2.5 (VSS), IC2.16 (VSSSMPS), IC2.31 (VSS), IC2.57 (VSS), IC2.58 (ANT_IN), IC2.59 (RF_OUT), IC2.60 (VSS), IC2.84 (VSS), IC2.86 (VSS), IC3.2 (GND), IC3.12 (GND), IC3.23 (GND), J1.A1 (GND), J1.A12 (GND), J1.B1 (GND), J1.B12 (GND), J1.SH (SHIELD), J2.1, J3.6 (GND), J04.8 (BS), J04.17 (VSS), J5.5, R1.2, R2.2, R3.1, R7.2, R8.2, SW1.1, TP8.1 (1_1), U1.2 (GND), U2.1 (GND), U2.3 (MODE), U2.6 (STOP), U3.4 (GND)
I2C1_SCL: IC1.14 (SCL), IC2.14 (PB8), J3.2 (SCL), R4.2, TP4.1
I2C1_SDA: IC1.13 (SDA), IC2.11 (PB9), J3.1 (SDA), R5.1, TP3.1
MCU_SPI_MISO: IC2.53 (PA6), IC3.6 (SPI_SDO), U3.2 (DO/IO_{1})
MCU_SPI_MOSI: IC2.52 (PA7), IC3.5 (SPI_SDI), J04.14 (SDI), U3.5 (DI/IO_{0})
MCU_SPI_SCK: IC2.54 (PA5), IC3.7 (SPI_SCK), J04.13 (SCLK), U3.6 (CLK)
NPM_GPIO0: IC1.7 (GPIO0), IC2.39 (PB6)
NTC: IC1.18 (NTC), J2.2
unnamed: C14.1, D1.1 (K), D2.2 (A)
unnamed: C14.2, D3.2 (A), L3.2, Q1.3 (D)
unnamed: IC1.5 (SW2), L2.2
unnamed: C10.1, IC1.22 (VBUSOUT)
unnamed: IC1.16 (VSET2), R1.1
unnamed: IC2.13 (PH3-BOOT0), R3.2, TP1.1 (1_1)
unnamed: C28.2, J04.18 (VDD)
unnamed: C21.2, J04.5 (VGH)
unnamed: C20.2, J04.4 (VGL)
unnamed: C23.2, J04.19 (VPP)
unnamed: C27.2, J04.20 (VSH)
unnamed: C24.2, J04.22 (VSL)
unnamed: L1.1, U2.7 (SW)
unnamed: R2.1, U2.5 (VSET)
P_USBD+: IC2.29 (PA12), U1.4 (I/O2)
P_USBD-: IC2.30 (PA11), U1.6 (I/O1)
SECURE_CSN: IC2.50 (PA8), IC3.8 (SPI_CSN)
SHPHLD: IC1.15 (SHPHLD), SW1.3
SWD_CLK: IC2.26 (PA14), J5.4
SWD_IO: IC2.25 (PA13), J5.2
SWD_O: IC2.21 (PB3), J5.6
SWD_RESET: C12.1, IC2.10 (NRST), J5.3
TOUCH_INT: IC2.24 (PC12), J3.5 (INT)
TOUCH_RST: IC2.23 (PC11), J3.4 (RST)
USBD+: J1.A6 (D+), J1.B6 (D+), U1.3 (I/O2)
USBD-: J1.A7 (D-), J1.B7 (D-), U1.1 (I/O1)
VBAT: C9.1, IC1.19 (VBAT), J2.3, TP7.1 (1_1)
VBUS: C3.1, IC1.21 (VBUS), J1.A4 (VBUS), J1.A9 (VBUS), J1.B4 (VBUS), J1.B9 (VBUS), TP2.1 (1_1), U1.5 (VBUS)
VSYS: C1.2, C5.1, C7.1, IC1.4 (PVDD), IC1.20 (VSYS), TP5.1 (1_1), U2.2 (VIN), U2.4 (EN)

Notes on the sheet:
TAG CONNECT SWD
DECOUPLING CAPACITOR
JST BAT CONN
EINK DRIVER
Test Points
EXTERNAL FLASH
POWER BUTTON
USB TYPE C
EINK FPC
POWER MANAGEMENT
SECURE ELEMENT
EINK TOUCH

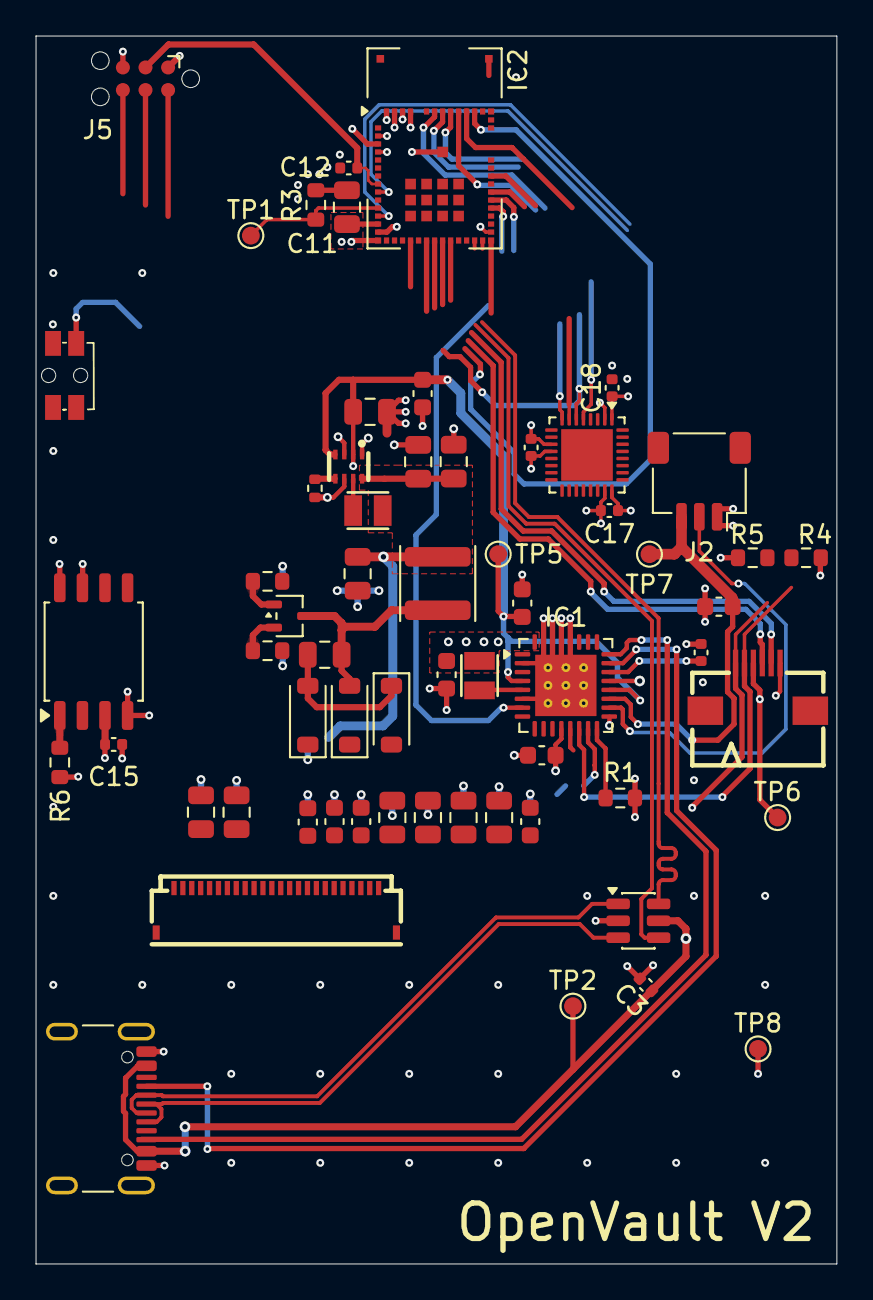
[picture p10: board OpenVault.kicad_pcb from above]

Board: 4 copper layers, 45.0 x 69.0 mm, 61 parts (0 on the bottom side), 51 nets.

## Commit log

2026-03-23 Working working
    [OpenVault.kicad_sch]
2026-03-23 tag connect
    [OpenVault.kicad_sch]
2026-03-23 all parts placed
    [OpenVault.kicad_sch]
2026-04-04 lot of work
    [.step, .stl, FPC-SMD_24P-P0.50_HC-FPC-05-09-24RLTAG.step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]
2026-04-26 some hardware chagnes
    [OpenVault.kicad_pcb, OpenVault.kicad_sch, V1_bom.csv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]
2026-04-28 final before v2
    [OpenVault.kicad_pcb, OpenVault.kicad_sch]
2026-08-01 Add VSON-8 3D model and production files
    Add a STEP 3D model and KiCad footprint for the VSON-8 package, plus a Vias directory. Add production outputs (Hardware/production/V3.zip, V3_bom.csv, V3_designators.csv, V3_positions.csv) and update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
    [OpenVault.kicad_pcb, OpenVault.kicad_sch, V3_bom.csv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]
2026-09-01 Add component datasheets and ignore editor local history
    Datasheets: GDEY027T91 e-paper, SSD1680 driver, Si1308EDL MOSFET,
    TPS62840 buck converter, W25Q128JV flash.
